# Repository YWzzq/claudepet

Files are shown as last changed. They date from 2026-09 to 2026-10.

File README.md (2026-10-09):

# AgentPet

桌面 AI Agent 状态摆件：电脑端 Claude Code / Codex 的状态经局域网 Wi-Fi 推到
ESP32-S3，通过 1.54" ST7789（240×240）表情屏幕和板载 RGB 灯显示当前状态。

支持状态配方管理、屏幕表情预览、自定义事件绑定和多会话优先级仲裁。
当前外壳为 **V5.1 像素方块版**，已完成软件几何检查，准备进行首轮打印试装。

## 当前外观与装配

下图是按硬件尺寸图生成的 CAD 模型预览。屏幕显示区构成桌宠的脸，开发板放在底层，双 USB 从右侧接线，后盖可拆卸。

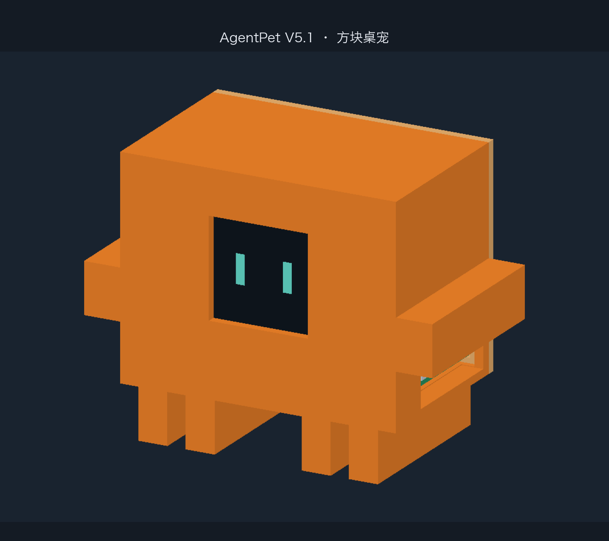
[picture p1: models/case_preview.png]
AgentPet V5.1 外壳模型预览


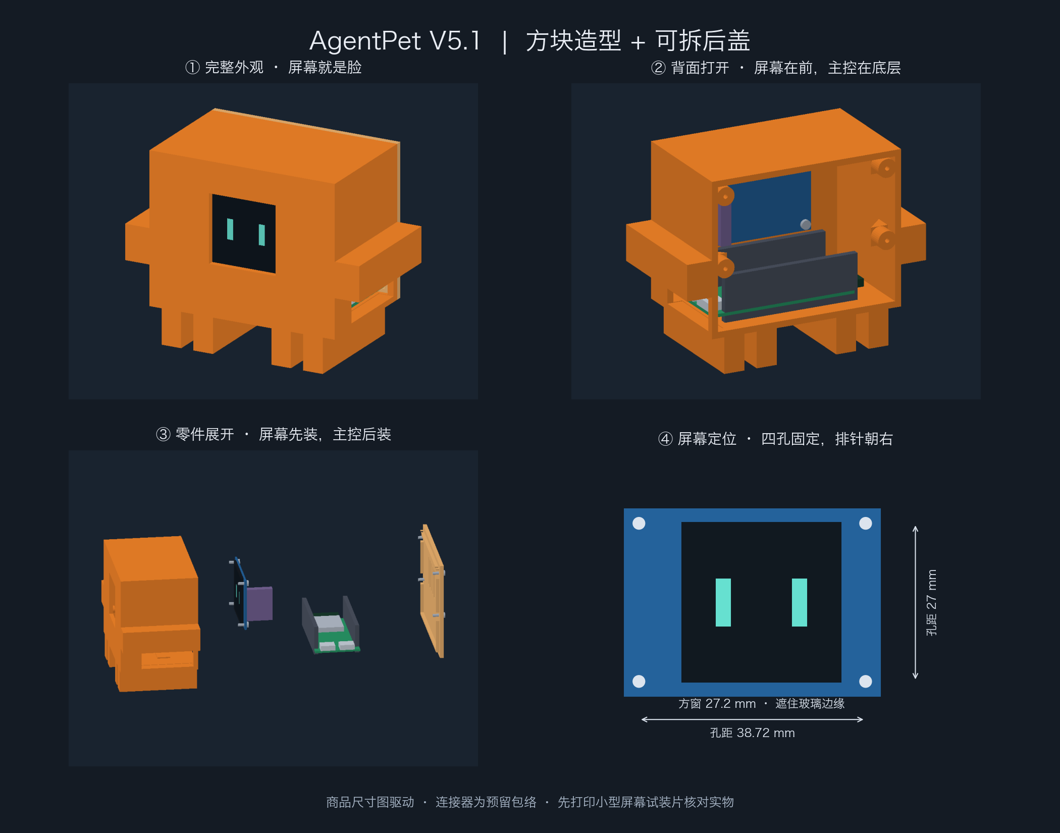
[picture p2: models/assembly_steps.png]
AgentPet V5.1 外观、内部布局、零件展开与屏幕孔位


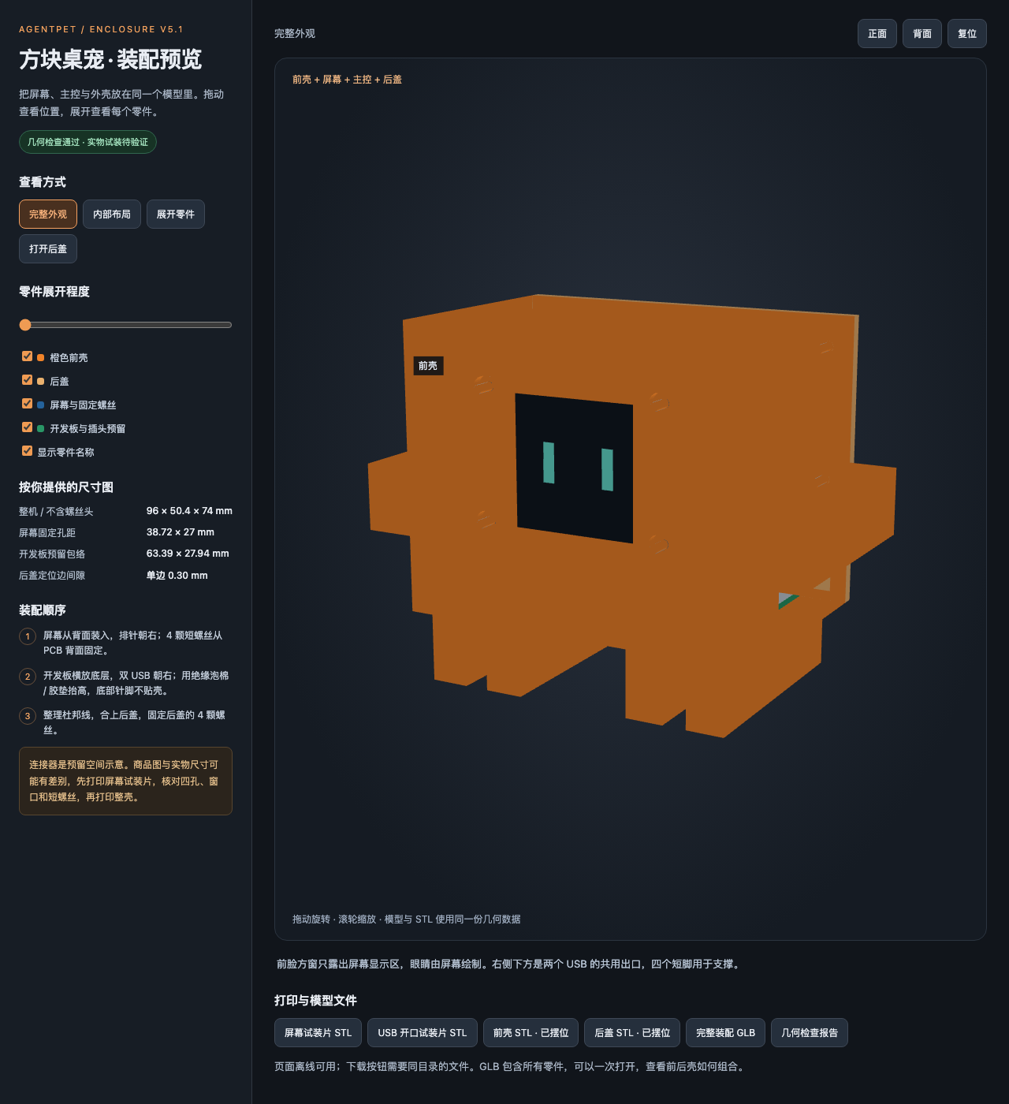
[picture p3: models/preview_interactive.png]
交互式装配预览页面


- [外壳与装配说明](models/README.md)
- [打印店专用包 V5.1](models/agentpet_print_shop_v5_1.zip)：两块试装片、前后壳、打印说明和装配图。
- [完整模型与源文件包 V5.1](models/agentpet_case_v5_1.zip)
- [完整装配 GLB](models/agentpet_assembly.glb)：一个文件查看全部零件。

下载仓库后，直接用浏览器打开 `models/assembly_preview.html`，可旋转、隐藏外壳、展开零件。
也可在项目根目录运行 `python3 -m http.server 8776 --bind 127.0.0.1 --directory models`，
然后访问 [本地装配预览](http://127.0.0.1:8776/assembly_preview.html)。GitHub 文件页显示 HTML 源码，需要下载或本地运行才能交互。

**软件检查通过不等于实物已验证。** 建议先打印屏幕和 USB 开口试装片，确认孔位、显示区及线头配合，再打印整壳。

## 系统架构

电脑端判断事件对应哪个状态，硬件端根据状态配方驱动屏幕与灯光。
事件映射保存在电脑端 `bridge/mapping.json`；状态配方保存在设备 NVS，断电保留。

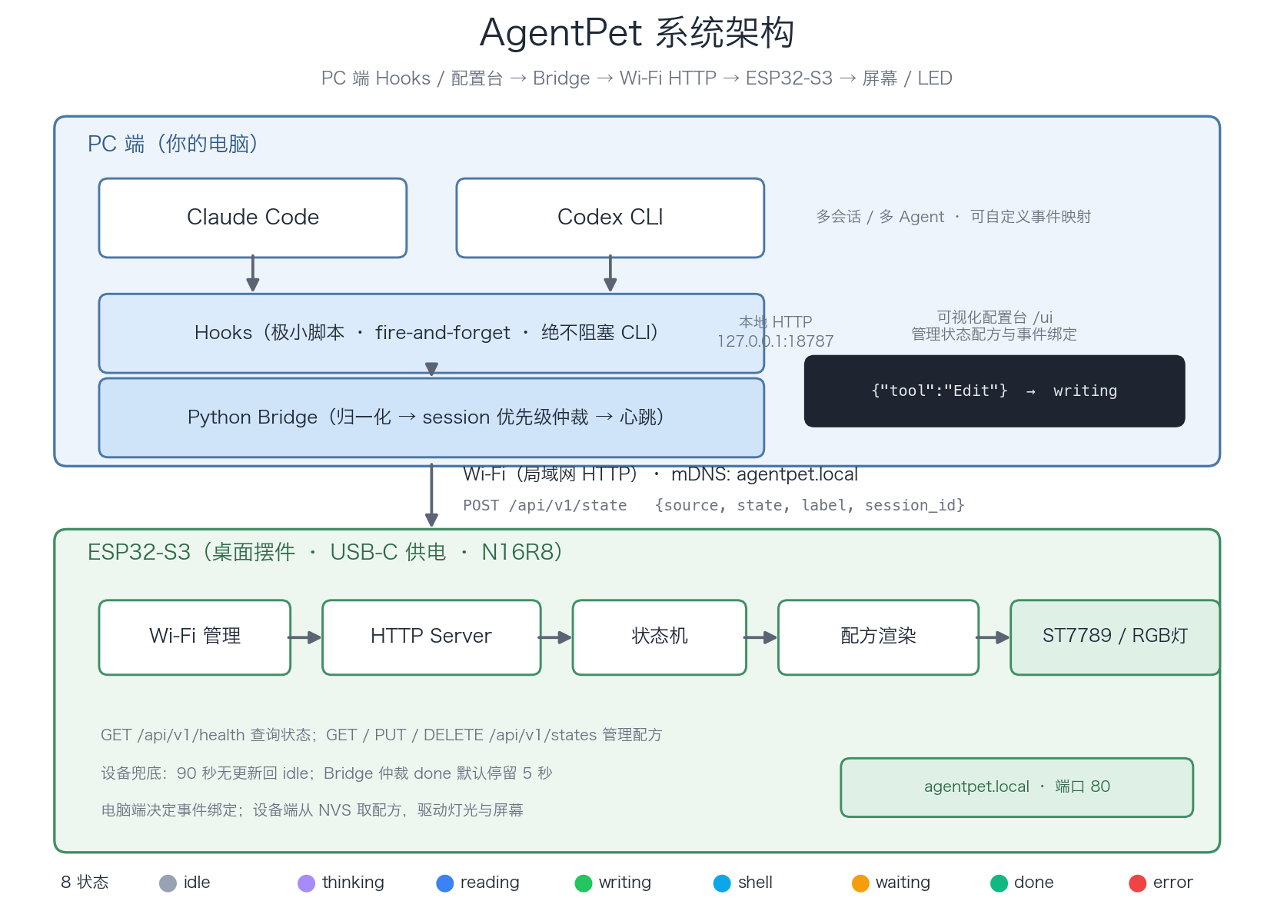
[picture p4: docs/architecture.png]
AgentPet 系统架构


## 目录结构

```
agentpet/
├── firmware/            # ESP32-S3 固件（PlatformIO + Arduino，已编译通过）
│   ├── platformio.ini
│   ├── wokwi.toml       # Wokwi 仿真入口
│   ├── diagram.json     # Wokwi 仿真接线
│   └── src/
│       ├── main.cpp     # Wi-Fi + mDNS + HTTP Server + 状态机
│       ├── pet_state.h  # 8 状态定义（与模拟器一一对应）
│       ├── display.cpp  # 矢量表情逐帧渲染（黑底彩五官，整帧推屏防闪烁）
│       ├── config.h     # 引脚 / 超时 / 设备名 / 显示开关
│       └── secrets.h.example  # 复制为 secrets.h 填 Wi-Fi
├── simulator/           # 浏览器表情模拟器（纯静态，直接打开）
├── bridge/              # Python Bridge（事件驱动推送）
│   ├── agentpet_bridge.py   # 规则引擎归一化 + session 仲裁 + 心跳
│   ├── mapping.json         # 事件→状态映射 / 优先级 / 超时（改文件热加载）
│   ├── webui.html           # 可视化配置台（bridge 自动托管）
│   └── test_bridge.py       # 单元测试（python3 test_bridge.py）
├── hooks/               # Claude Code / Codex hooks
│   ├── agentpet_hook.py     # 通用转发脚本（fire-and-forget，离线落盘）
│   └── install_hooks.py     # 一键安装器（自动备份、幂等）
├── tools/
│   └── virtual_device.py    # 虚拟 ESP32：终端表情脸，不插板子跑通全链路
├── models/              # V5.1 外壳、STL/GLB、装配预览、检查报告和打印包
│   ├── build_case.py          # 尺寸与结构的唯一来源
│   ├── render_assembly.py     # 装配图与交互预览生成器
│   ├── final_print_audit.py   # 独立检查导出的 STL / GLB
│   └── README.md             # 尺寸依据、装配与打印说明
└── docs/                # 系统架构图与生成脚本
```

## 快速开始

### 1. 表情模拟器（不需要硬件）

直接用浏览器打开 `simulator/index.html`：
8 个状态按钮切换、3 秒自动轮播、可调 `label` 和 `source`，
下方实时显示对应的 `POST /api/v1/state` 请求体。

### 2. 固件

```bash
pip install platformio
cp firmware/src/secrets.h.example firmware/src/secrets.h   # 填入 Wi-Fi
cd firmware
pio run -t upload            # 烧录（CH343P 串口，可能需要 -u 指定端口）
pio device monitor           # 看日志
```

### 3. Python Bridge（V0.5）

```bash
cd bridge
python3 test_bridge.py            # 16 个单元测试
python3 agentpet_bridge.py --demo # 演示：双会话 + 优先级抢占 + done 过期（约 16s）
python3 agentpet_bridge.py        # 正常运行，推送 http://agentpet.local
python3 agentpet_bridge.py --host 192.168.1.23   # 或手动指定设备 IP
```

手动喂一个事件（模拟 hook）：

```bash
curl -X POST http://127.0.0.1:18787/hook \
     -d '{"hook_event_name":"PreToolUse","tool_name":"Edit","session_id":"test"}'
curl http://127.0.0.1:18787/health
```

仲裁规则：`waiting > error > done > writing > shell > reading > thinking > idle`，
同优先级新的赢；done 停留 5s 后自动让位；90s 无事件的 session 丢弃。
20s 心跳兜底喂固件的 90s 超时。事件到达即时推送（事件驱动，非轮询）。

### 4. Hooks 一键安装（V0.6/V0.7）

```bash
python3 hooks/install_hooks.py             # claude + codex 都装
python3 hooks/install_hooks.py --claude    # 只装 Claude Code
```

- 安装器自动备份原配置（`.bak-时间戳`），只增不删、重复运行幂等
- hook 脚本 0.5s 超时 fire-and-forget，bridge 不在线时事件落盘
  `~/.agentpet/missed-hooks.jsonl`，绝不拖慢 CLI
- 端口冲突时：bridge `--port XXXX`，并设环境变量
  `AGENTPET_BRIDGE=http://127.0.0.1:XXXX/hook`
- 验证：开着 `bridge --dry-run`，正常使用 Claude Code，就能看到真实状态流

### 5. 用 curl 直接驱动固件（V0.4 验收，不经过 bridge）

```bash
curl -X POST http://agentpet.local/api/v1/state \
     -H 'Content-Type: application/json' \
     -d '{"source":"claude","state":"writing","label":"Edit"}'

curl http://agentpet.local/api/v1/health
```

### 6. 虚拟设备：不插板子跑通全链路

```bash
python3 tools/virtual_device.py 8080                                # 终端 A：虚拟 ESP32
AGENTPET_HOST=127.0.0.1:8080 python3 bridge/agentpet_bridge.py      # 终端 B：bridge 指向它
# 正常使用 Claude Code / Codex（或用 curl 喂 hook），终端 A 实时画表情脸
```

### 7. Wokwi 仿真（没有板子也能跑固件）

```bash
# 1) secrets.h 里 SSID 填 Wokwi-GUEST，密码留空
# 2) 编译 + 启动仿真（二选一）：
cd firmware && pio run
wokwi-cli                           # 命令行方式（需先安装 CLI、配置 token）
# 或 VS Code 装 Wokwi 扩展，打开 diagram.json 点播放
```

说明：
- **服务器仿真已部署**：wokwi-cli v0.26.1 装在服务器 `/usr/local/bin`，
  固件与配置在 `/root/agentpet/`。拿到 token 后：
  `WOKWI_CLI_TOKEN=<token> /root/agentpet/run_sim.sh`
- 本地跑也可以：`npm i -g` 不可用（CLI 不在 npm 上），用官方脚本
  `curl -L https://wokwi.com/ci/install.sh | sh`
- Wokwi 没有官方 ST7789 零件，`diagram.json` 用 `wokwi-ili9341` 代演
  （ST77xx 命令集兼容，社区通行做法；仿真屏下方留黑边属正常现象）
- wokwi-cli 自带虚拟 IoT Gateway，仿真里的固件可以访问外网乃至本机 bridge
- 仿真若颜色反色，调 `display.cpp` 里初始化后的反转设置即可

## 状态协议 v1

`POST /api/v1/state`

```json
{"source": "claude", "state": "writing", "label": "Edit", "session_id": "abc123"}
```

| state | 含义 | 表情（黑底 = 屏幕不显示，亮起的只有彩色五官） |
|---|---|---|
| idle | 空闲/睡觉 | 灰蓝：闭眼 ∪ + 飘 z |
| thinking | 思考 | 紫：眼神飘 + 平嘴 + "..." |
| reading | 读取代码 | 蓝：眼睛左右扫 |
| writing | 编辑/写代码 | 绿：眼睛向下 + o 嘴 |
| shell | 执行命令 | 青：嘴 = `> _` 提示符闪烁 |
| waiting | 等待确认/授权 | 琥珀：瞪大眼 + 嘴 = 大问号 |
| done | 任务完成 | 翠绿：笑眼 ∩ + 大笑嘴（5s 后自动回 idle） |
| error | 异常/失败 | 红：X 眼 + 波浪嘴 + 轻微抖动 |

`GET /api/v1/health` 返回：state / state_for_s / source / label / session_id /
uptime_s / wifi / rssi / heap / ip。

兜底规则：90 秒没有任何事件自动回 idle；done 停留 5 秒回 idle。

## 状态配方系统（V1.0）

板子内置"配方库"（NVS 持久化，断电不丢），出厂预置 8 个状态，支持动态增删改：

```bash
# 列出板上全部状态
curl http://agentpet.local/api/v1/states
# 新增自定义状态（灯光 + 屏幕）
curl -X PUT http://agentpet.local/api/v1/states/tea \
     -H 'Content-Type: application/json' \
     -d '{"led":{"color":"#3BC4E8","mode":"breath","period":1500},"screen":{"color":"#3BC4E8","eye":"happy"}}'
# 查看 / 删除
curl http://agentpet.local/api/v1/states/tea
curl -X DELETE http://agentpet.local/api/v1/states/tea
```

灯效 mode：`steady` 常亮 / `breath` 呼吸 / `blink` 闪烁 / `double` 双闪，
period 50~20000ms（steady 忽略）。预置状态可覆盖更新。

**bridge 事件映射**同样数据化（`bridge/mapping.json`）：规则（source/event/tool 通配/字段匹配）
→ 状态、优先级表、超时。改文件保存即热加载，不用重启。

### 可视化配置台（V1.2）

bridge 跑起来后，浏览器打开 **http://localhost:18787/ui**：

- 状态配方：管理一份状态中的灯光与屏幕配置，可新增、编辑、删除和试播。
- 灯光预览：颜色、灯效、周期；屏幕预览：五官、颜色及动画参数。
- 事件绑定：编辑 `mapping.json` 的事件映射与优先级，保存即热加载。
- 配方保存到板子 NVS；界面中的预览与试播用于检查效果，保存用于持久化。
- 板子固件已开 CORS，网页可跨域直连板子；自动从 bridge 获取板子 IP

## 屏幕接线（交接文档第 3 节）

| ST7789 | ESP32-S3 | 备注 |
|---|---|---|
| VCC / GND | 3V3 / GND | |
| SCK | GPIO12 | |
| MOSI | GPIO11 | |
| CS | GPIO10 | |
| DC | GPIO13 | |
| RST | GPIO14 | |
| BLK | 3V3（V0） | 后续可改 GPIO21 PWM 调光 |

避开：GPIO48（板载 RGB）、GPIO0（BOOT）、GPIO19/20（USB）、GPIO43/44（串口）、
GPIO35/36/37（N16R8 Octal PSRAM 占用）。

## 3D 打印外壳（V5.1）

已按屏幕与 ESP32-S3 商品尺寸图重建像素方块外壳，包含屏幕四孔固定、主控胶垫区域、双 USB 共用出口和可拆后盖。
V5.1 将主控向 USB 一侧移近 3.5 mm，USB 共用开口为 **32.34 × 12 mm**，接口后缩约 **2.8 mm**；后盖螺柱加入斜撑。

| 项目 | 当前设计 |
|---|---|
| 整机最大尺寸 | 96 × 50.4 × 74 mm，不含螺丝头 |
| 屏幕固定孔距 | 38.72 × 27 mm |
| 屏幕窗口 | 27.2 × 27.2 mm，遮住玻璃边缘 |
| 后盖定位边间隙 | 单边 0.30 mm |
| 屏幕 / 后盖螺丝 | Ø2 × 5 mm / Ø2 × 6 mm，自攻，各 4 颗 |
| 软件检查 | 54 项模型检查 + 29 项导出文件检查通过 |

打印文件按顺序使用：

1. [屏幕试装片](models/screen_fit_coupon.stl)与 [USB 开口试装片](models/usb_fit_coupon.stl)：先验证实物。
2. [前壳打印文件](models/agentpet_case_front_print.stl)与 [后盖打印文件](models/agentpet_case_back_print.stl)：试装确认后，各打印一件。文件已摆位。

首轮建议橙色 PLA / FDM、0.2 mm 层高、3 道壁、100% 比例。
打印店需要检查切片预览并按需加局部支撑；不能仅凭 STL 闭合就判断免支撑。
详见 [打印店交接说明](models/print_shop_instructions.txt)、[尺寸与装配说明](models/README.md)。
实际打印公差、插头、线材和螺丝配合仍待试装确认。

重新生成和检查模型：

```bash
python3 -m venv /tmp/agentpet-cad
/tmp/agentpet-cad/bin/pip install -r models/requirements.txt
/tmp/agentpet-cad/bin/python models/build_case.py
/tmp/agentpet-cad/bin/python models/render_assembly.py
/tmp/agentpet-cad/bin/python models/final_print_audit.py
```

## 路线图

- [x] V0.1 固件骨架：Wi-Fi + mDNS + HTTP + 状态机（编译通过）
- [x] V0.2 浏览器 240×240 表情模拟器（8 状态黑底彩五官，动画可调）
- [x] V0.3 ST7789 显示驱动与真屏配置（`AGENTPET_HAS_DISPLAY=1`；当前旋转配置为 2）
- [x] V0.4 固件矢量表情：与模拟器同一套参数移植为 Adafruit GFX（编译通过，真机观感待验证）
- [x] V0.5 Python Bridge：归一化 + session 优先级仲裁 + 心跳 + mDNS 解析（16 测试通过，事件驱动即时推送）
- [x] V0.6 Claude Code hooks：7 事件转发 + 一键安装器（沙箱安装 + 端到端验证通过）
- [x] V0.7 Codex hooks：事件归一化 + 安装器（Codex 配置格式随版本演进，不生效时按官方文档微调 `hooks/install_hooks.py`）
- [x] V0.8 外壳 V5.1：模型、装配预览、试装片、前后壳、打印包与软件检查
- [ ] V0.8 外壳实物打印与试装
- [ ] 后续动画打磨、可选电池版
- [x] V1.0 状态配方系统：配方 NVS 持久化 + GET/PUT/DELETE /states API + bridge 规则引擎（mapping.json 热加载）
- [x] V1.1 屏幕表情配方化（固件按配方 `screen` 字段驱动表情）
- [x] V1.2 可视化配置台（配方管理、屏幕 / LED 预览、事件绑定）

## 主要参考

- [clawd-mochi-esp32s3](https://github.com/TangYifu/clawd-mochi-esp32s3)：硬件完全一致
  （ESP32-S3 + 1.54" ST7789 240×240），ST7789 初始化参数与点屏细节第一参考
- [cc-mochi](https://github.com/alvis-HaoH/cc-mochi)：Claude/Codex hooks 一键安装器、
  事件归一化映射表、session 优先级、表情预览工具思路
- [VibeMonitor](https://github.com/austingregoryus/VibeMonitor)：Python Bridge、局域网 HTTP
- [Tiny Engineer](https://github.com/jamro/tiny-engineer)："设备只懂 REST" 的简单 API 设计
- [AgentDeck](https://github.com/puritysb/AgentDeck)：未来多 Agent / 多设备架构参考
- HachimoDock：桌宠 UI 与产品形态参考

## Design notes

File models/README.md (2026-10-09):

# AgentPet V5.1 外壳与试装

这一版按用户提供的橙色像素摆件外形和两张硬件尺寸图重建：平顶方块身体、两侧凸块、四只短脚。前脸的眼睛由 ST7789 绘制，外壳不另外挖眼睛孔。

**当前状态：模型几何检查通过，尚未经过实物打印和试装。** 商品尺寸图不是对用户实物的测量；先用屏幕试装片确认，不把软件检查当成“肯定刚好能装”的证明。

## 先看位置

直接双击 `assembly_preview.html`，离线也能旋转模型。切换“内部布局”“展开零件”“打开后盖”，用复选框单独隐藏零件。所有几何与 STL 同源，不是另外画的效果图。

- `assembly_steps.png`：外观、打开后盖、零件展开、屏幕定位四张图。
- `agentpet_assembly.glb`：完整装配，包含前后壳、屏幕、主控及螺丝示意。一次打开这个文件即可看到所有零件，已经转换成 glTF 的 Y 向上坐标。
- 两个 `*_print.stl` 是打印摆位；两个没有 `_print` 的 STL 保留装配坐标。`agentpet_case_both.stl` 是分开摆在打印床上的两件，不是粘成一体的外壳。

## 尺寸依据与修正

尺寸来自本次用户附件。保留足够精度定位孔位；实物精度仍需核对。

| 项目 | 本版采用 | 依据或处理 |
|---|---:|---|
| 屏幕 PCB | 32 × 43.72 mm | 参数表宽约 32，尺寸图长 43.72；31.52 是 BL 尺寸，不当成 PCB 宽度 |
| 屏幕有效显示区 AA | 27.72 × 27.72 mm | 参数表与尺寸图一致 |
| AA 相对 PCB | 从排针端 6.45 mm；从侧边 2.14 mm | 尺寸图；横置后按 AA 中心对齐方窗，PCB 中心偏左 1.55 mm |
| 四孔孔距 | 38.72 × 27.00 mm | 尺寸图；V4 的 26.52 已纠正 |
| 屏幕孔径 | Ø2.00 mm | 图中 4-Ø2.00；Ø3.80 是焊盘外圈，不能当孔径 |
| 屏模块厚度 | 2.58 mm | 参数表；PCB 自身 1.2 mm 来自侧视图 |
| 主控最大长度 | 63.389 mm | 图中 2495.63 mil × 0.0254，包含天线伸出部分 |
| 主控 PCB 长度 | 57.15 mm | 图中 2250 mil；53.34 mm 是排针跨度，不能当板长 |
| 主控最大宽度 | 27.94 mm | 尺寸图；排针中心跨度 25.40 mm |
| 完整外壳最大尺寸 | 96 × 50.4 × 74 mm | 含侧凸块、后盖与脚，不含螺丝头 |
| 主体 / 主腔宽度 | 76 / 71.2 mm | 主控总长两侧合计余量约 7.81 mm |
| 前脸窗口 | 27.2 × 27.2 mm | 遮住玻璃边缘，AA 每边遮挡 0.26 mm；并非露出整个 27.72 mm |
| 后盖定位边间隙 | 每边 0.30 mm | 打印配合假设，需试装 |

V5.1 最终检查修正：主控向右移 3.5 mm，将接口后缩从约 6.3 mm 减少到约 2.8 mm；USB 开口加宽加高，后盖螺柱增加约 45° 斜撑。

屏幕横置，排针在右边。主控横躺，天线在左边，两个 USB 朝右边。右侧是共用的约 32.34 × 12 mm 开口，两个插口都可用；插口后缩约 2.8 mm，插头是否够长仍需用实际 USB 线确认。

## 焊排针与杜邦线的预留

用户已确认：排针焊好，采用母头杜邦线。

模型预留主控 PCB 上方 14 mm 的排针 / 母头包络，下方 2.6 mm 的针脚包络；屏幕背面预留 16 mm 插头包络。主控插头最高面与屏幕插头最低面之间约 2.64 mm。灰色长条和紫色块是这些包络，**不是实际新增的塑料零件，也不是对每个接插件的精细复刻**。

主控 PCB 下表面设在 Z=20 mm，腔底 Z=16.4 mm，相差 3.6 mm。底部两块绝缘垫台高 0.8 mm，因此需要约 2.8 mm 的绝缘胶垫 / 泡棉或适当胶柱抬高板子；不要让针脚直接接触底壳。接插件实际高于预留值时，修改源文件参数后重生成。

导线没有建模。用短杜邦线从屏幕右側插头往空余侧腔走，留自然弯曲，不压排线、不拉住屏幕、不在后盖定位边内夹线；闭盖是否顺畅需要实物验证。

## 推荐的试装顺序

1. **先打印 `screen_fit_coupon.stl`**，约 50 × 37 × 4.38 mm。它复用了本版的方窗、四个螺柱和底孔。将屏幕横置、排针朝右，核对四孔是否同时对齐、玻璃是否碰柱、显示区是否正确露出。

   同时可打印 `usb_fit_coupon.stl`（约 40.34 × 20 × 2.4 mm），检查实际 USB 线塑料头能否穿过开口；它只验证开口，不验证插口深度。

2. 试装通过后打印 `agentpet_case_front_print.stl` 和 `agentpet_case_back_print.stl`。按毫米、100% 比例，不自动缩放。前壳面朝打印床，后盖外表面朝打印床，文件已摆好。
3. 从背面放入屏幕，玻璃朝窗口，4 颗螺丝从 PCB 背面拧入前壁螺柱。模型按 **Ø2 × 5 mm 短自攻螺丝**建空间，Ø1.7 mm 底孔。轻拧，不以螺丝强行拉平屏幕；不同自攻牙型和头径需在试装片上验证。原版的 6 mm 屏幕螺丝可能穿透前脸，不能直接照用。
4. 安放绝缘胶垫后，将开发板从后开口横放入底层；两个 USB 对着右侧开口。接好线，检查针脚不碰底壳、胶不覆盖插口或天线。
5. 整理杜邦线，插入后盖定位边，4 颗 **Ø2 × 6 mm 自攻螺丝**固定后盖。后盖螺柱在主控上方，避免挡住板子放入。

橙色 PLA 可作为首轮样件，层高 0.2 mm、3 道壁。前壳横跨侧边 USB 开口，请打印店检查切片预览，在 USB 开口桥接处按需加局部支撑；若支撑需要从前壁内侧生长，应允许支撑接触模型，不能只限定“仅打印床”；本版**没有承诺完全免支撑**。这两件的分开摆位约 184 × 74 mm，需要对应的打印床空间，也可各印一件。

## 软件检查覆盖什么

保存后的 STL/GLB 又通过 `final_print_audit.py` 独立检查，报告在 `final_print_audit.json`。包括实际输出的闭合性、摆位、后盖 ±0.28 mm 偏移配合、窗口与 USB 通道、四个盲底孔和屏幕螺丝末端。没有在本机运行实际打印机切片；打印店应按 `print_shop_instructions.txt` 检查切片支撑。

`fit_report.json` 包含实体闭合性、连通性、孔距、窗口范围、板子含天线尺寸、前后壳与各硬件包络的相交体积、屏幕/主控相互碰撞、USB 通道和后盖定位边。装入路径从背面到最终位置，按 1 mm 步长抽样检查，顺序是 **先屏幕、再主控、后盖最后**。

仍需实物验证：商品图与实物差异、打印收缩与孔径、胶垫、杜邦线弯曲、USB 插头外形与插入深度、螺丝牙型及长度、抗拉强度和散热。孔距通过与水密 STL 不能替代这些验证。

## 重生成

在项目根目录运行，或用绝对路径运行两个脚本；输出路径始终在 `models/`：

```sh
python3 -m venv /tmp/agentpet-cad
/tmp/agentpet-cad/bin/pip install -r models/requirements.txt
/tmp/agentpet-cad/bin/python models/build_case.py
/tmp/agentpet-cad/bin/python models/render_assembly.py
/tmp/agentpet-cad/bin/python models/final_print_audit.py
```

`build_case.py` 是尺寸与结构唯一来源；`agentpet_case.scad` 仅加载生成的 STL 用于查看。改变尺寸后应重新运行两个脚本和几何检查。手机窄屏也能打开预览，桌面浏览器能更方便地同时看到模型和控制区。

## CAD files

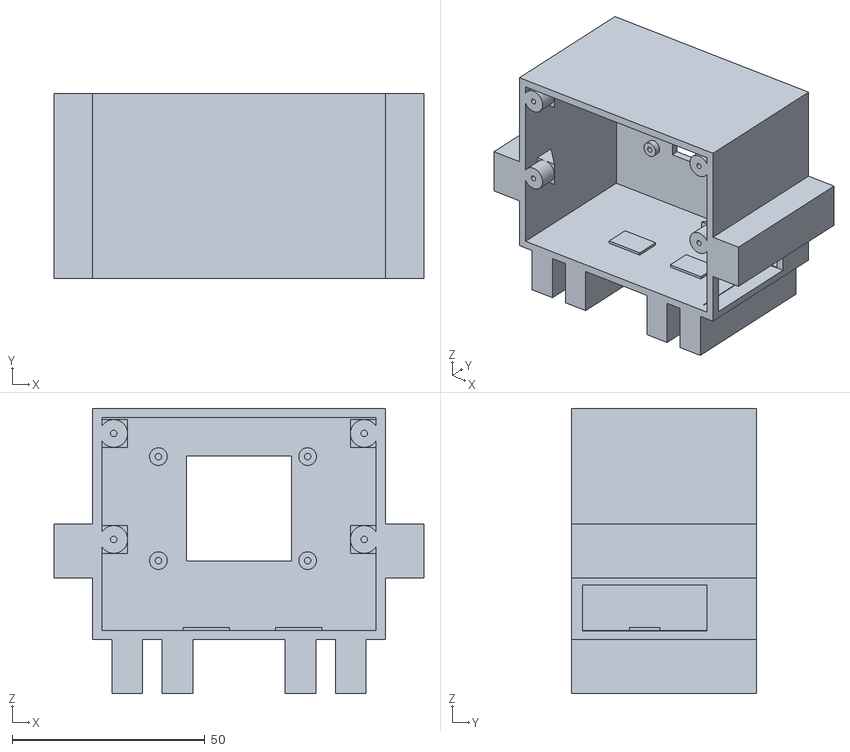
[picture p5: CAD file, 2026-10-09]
models/agentpet_case_front.stl
96.0 x 48.0 x 74.0

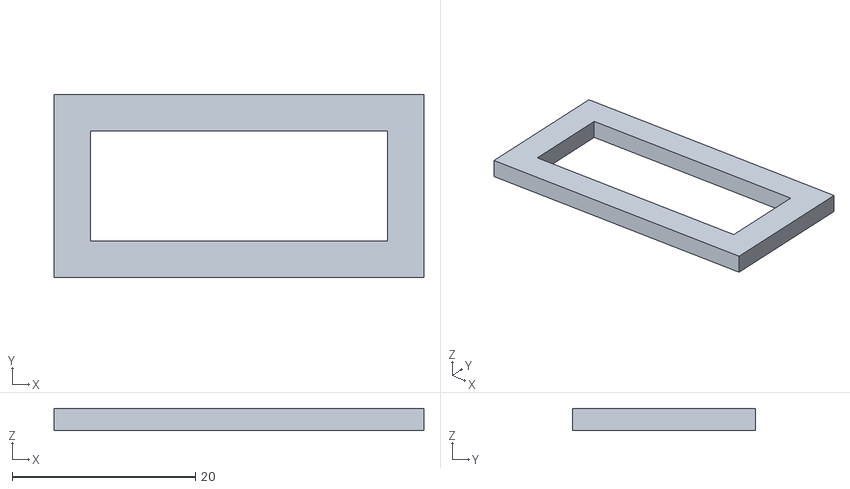
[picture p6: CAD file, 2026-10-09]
models/usb_fit_coupon.stl
40.3 x 20.0 x 2.40

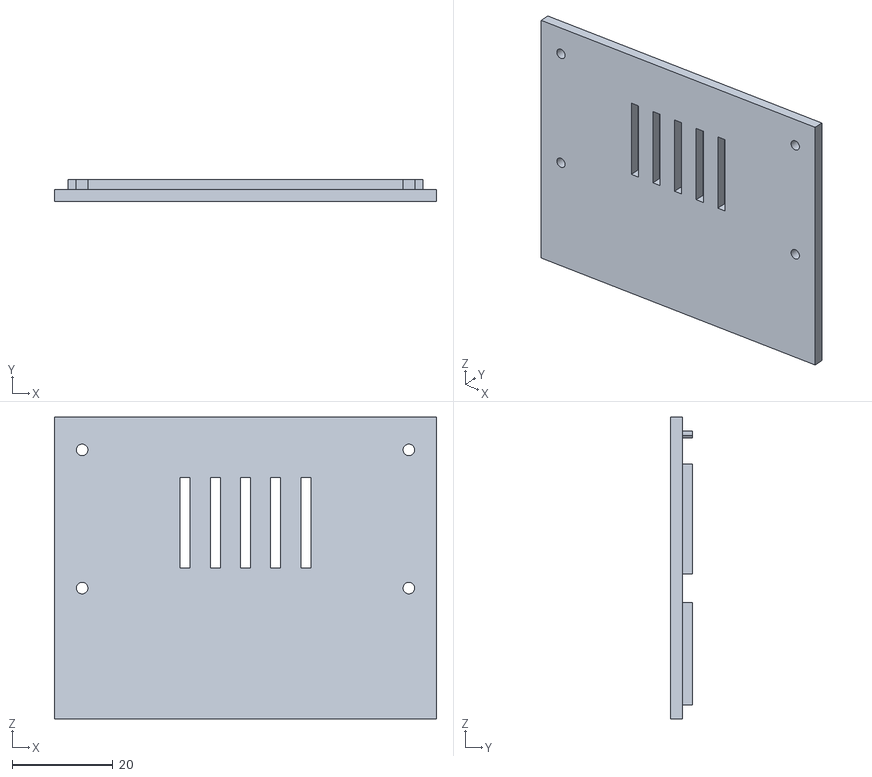
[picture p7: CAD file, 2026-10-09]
models/agentpet_case_back.stl
76.0 x 4.40 x 60.0

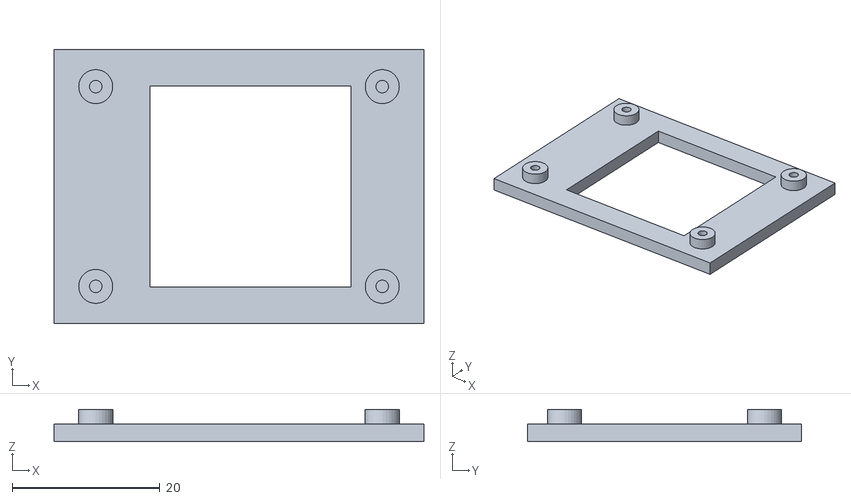
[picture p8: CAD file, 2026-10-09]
models/screen_fit_coupon.stl
50.0 x 37.0 x 4.38

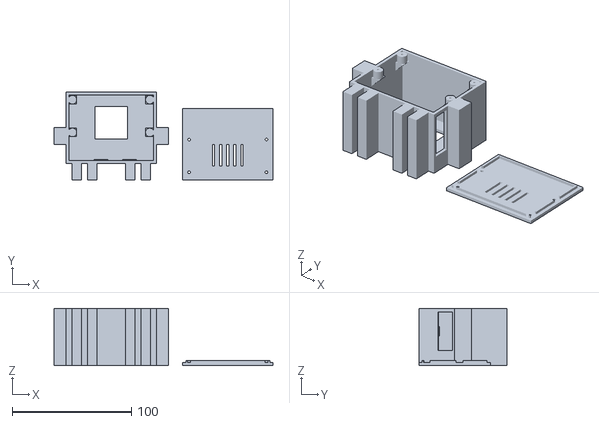
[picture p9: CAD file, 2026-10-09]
models/agentpet_case_both.stl
184.0 x 74.0 x 48.0

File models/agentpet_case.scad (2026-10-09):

// V5.1 viewer, mm. Dimension source: build_case.py; run it to regenerate meshes.
// part = "layout" | "assembly" | "front" | "back" | "coupon".
part = "layout";
if (part == "layout") import("agentpet_case_both.stl");
if (part == "assembly") {
  color("DarkOrange") import("agentpet_case_front.stl");
  color("Wheat") import("agentpet_case_back.stl");
}
if (part == "front") import("agentpet_case_front.stl");
if (part == "back") import("agentpet_case_back.stl");
if (part == "coupon") import("screen_fit_coupon.stl");

if (part == "usb-coupon") import("usb_fit_coupon.stl");

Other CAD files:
models/agentpet_case_front_print.stl
models/agentpet_case_back_print.stl

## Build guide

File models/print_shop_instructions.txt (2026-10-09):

AgentPet V5.1 打印店交接说明（2026-10-09）

工艺：FDM。材料：橙色 PLA。单位：毫米，100% 比例，不缩放。
打印一套设备外壳，不打印 GLB 里的屏幕、主控、螺丝或插头占位块。

阶段一：先各印 1 件试装片
01_screen_fit_coupon.stl：50 × 37 × 4.38 mm，验证屏幕孔位、窗口与短螺丝。
02_usb_fit_coupon.stl：40.34 × 20 × 2.4 mm，验证 USB 线塑料头能否通过开口。
试装片已经摆平。试装成功后再打印整壳。

阶段二：整壳各 1 件
03_front.stl：前壳，打印摆位尺寸 96 × 74 × 48 mm。
04_back.stl：后盖，打印摆位尺寸 76 × 60 × 4.4 mm。
两个文件已摆位且最低面为 Z=0。前壳前脸朝下，后盖外表面朝下。
整机组装尺寸 96 × 50.4 × 74 mm，不含螺丝头。

建议首轮参数：0.4 mm 喷嘴，0.2 mm 层高，3 道壁，顶底至少 4 层，15–20% 填充。
请打印店按实际机器切片确认，特别检查侧边 USB 开口的小桥接区域。
按需加局部支撑；支撑可以从模型内表面开始，不能只限定“仅打印床”。
后盖螺柱已经增加斜撑。不要填平 USB 口、屏幕窗口和后盖定位边。
保留原有孔位：前壳螺丝底孔 Ø1.7 mm，后盖通孔 Ø2.3 mm。
清理残余支撑、毛刺，避免强行扩大自攻底孔。

装配用料（不属于打印件）：
屏幕：Ø2 × 5 mm 短自攻螺丝，4 颗；先在试装片上验证牙型和头径。
后盖：Ø2 × 6 mm 自攻螺丝，4 颗。
主控：绝缘泡棉胶 / 胶垫；在底部凸台上增加约 2.8 mm 高度，底面针脚留空。
装配顺序：屏幕先装，开发板横放底层且双 USB 朝右，理线，后盖最后固定。

本包通过软件几何及导出文件检查；实物尺寸与打印公差尚未试装验证。
这是首轮试装样件，不是已经过实物验证的量产文件。
请勿使用前一版 agentpet_case_v5.zip；本次应使用 V5.1 包。

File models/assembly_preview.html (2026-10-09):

AGENTPET / ENCLOSURE V5.1

# 方块桌宠 · 装配预览

把屏幕、主控与外壳放在同一个模型里。拖动查看位置，展开查看每个零件。

几何检查通过 · 实物试装待验证

## 查看方式

完整外观内部布局展开零件打开后盖

## 零件展开程度

显示零件名称

## 按你提供的尺寸图

整机 / 不含螺丝头96 × 50.4 × 74 mm屏幕固定孔距38.72 × 27 mm开发板预留包络63.39 × 27.94 mm后盖定位边间隙单边 0.30 mm

## 装配顺序

1屏幕从背面装入，排针朝右；4 颗短螺丝从 PCB 背面固定。

2开发板横放底层，双 USB 朝右；用绝缘泡棉 / 胶垫抬高，底部针脚不贴壳。

3整理杜邦线，合上后盖，固定后盖的 4 颗螺丝。

连接器是预留空间示意。商品图与实物尺寸可能有差别，先打印屏幕试装片，核对四孔、窗口和短螺丝，再打印整壳。

完整外观

正面背面复位

外观内部展开后盖

前壳 + 屏幕 + 主控 + 后盖

拖动旋转 · 滚轮缩放 · 模型与 STL 使用同一份几何数据

前脸方窗只露出屏幕显示区，眼睛由屏幕绘制。右侧下方是两个 USB 的共用出口，四个短脚用于支撑。

## 打印与模型文件

屏幕试装片 STLUSB 开口试装片 STL前壳 STL · 已摆位后盖 STL · 已摆位完整装配 GLB几何检查报告

页面离线可用；下载按钮需要同目录的文件。GLB 包含所有零件，可以一次打开，查看前后壳如何组合。

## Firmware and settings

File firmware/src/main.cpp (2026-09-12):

/**
 * AgentPet V1.0 固件
 * Wi-Fi + mDNS + HTTP + 配方驱动状态机
 *
 * 状态不再是写死的枚举：板子内置"配方库"（NVS 持久化，出厂预置 8 态），
 * 收到的 state 名字先查配方库，按配方渲染 LED 与屏幕。
 *
 * 路由：
 *   POST   /api/v1/state            {"state":"writing","source":"claude",...}
 *   GET    /api/v1/states           列出全部状态配方
 *   GET    /api/v1/states/<name>    查看单个配方
 *   PUT    /api/v1/states/<name>    新增/覆盖配方（存 NVS，断电不丢）
 *   DELETE /api/v1/states/<name>    删除配方
 *   GET    /api/v1/health           健康检查
 *
 * 烧录前：复制 src/secrets.h.example 为 src/secrets.h 并填入 Wi-Fi 信息
 */
#include <Arduino.h>
#include <ESPmDNS.h>
#include <WebServer.h>
#include <WiFi.h>
#include <ArduinoJson.h>

#include "config.h"
#include "display.h"
#include "pet_state.h"
#include "recipe_store.h"
#include "secrets.h"
#include "status_led.h"

WebServer server(HTTP_PORT);

RecipeStore gRecipes;
String gStateName = "idle";
String gSource, gLabel, gSession;
unsigned long gStateSince = 0;             // 当前状态开始时间
unsigned long gLastEvent = 0;              // 最近一次收到 state POST
String gRendered = "";                     // 上次已渲染的状态名

void setState(const String& name, const String& source, const String& label, const String& session) {
  gStateName = name;
  gSource = source;
  gLabel = label;
  gSession = session;
  gStateSince = gLastEvent = millis();

  // 配方驱动：查库取渲染参数（查不到回落 idle，理论上有 API 校验不会发生）
  StateRecipe sr;
  if (!gRecipes.get(name, sr)) gRecipes.get("idle", sr);
  ledApplyRecipe(sr.led);

  // 屏幕：配方参数驱动（内置表情表 + 配方 screen 覆盖）
  displaySetStateByName(name, label, sr.raw);
}

void handleState() {
  if (!server.hasArg("plain")) {
    server.send(400, "application/json", "{\"error\":\"missing body\"}");
    return;
  }
  JsonDocument doc;
  if (deserializeJson(doc, server.arg("plain"))) {
    server.send(400, "application/json", "{\"error\":\"invalid json\"}");
    return;
  }
  String name = String(doc["state"] | "");
  if (!gRecipes.has(name)) {
    server.send(404, "application/json",
                ("{\"error\":\"unknown state: " + name + "\"}").c_str());
    return;
  }
  setState(name, String(doc["source"] | ""), String(doc["label"] | ""),
           String(doc["session_id"] | ""));
  JsonDocument resp;
  resp["ok"] = true;
  resp["state"] = name;
  String out;
  serializeJson(resp, out);
  server.send(200, "application/json", out);
}

void handleStatesList() {
  server.send(200, "application/json", gRecipes.listJson());
}

// /api/v1/states/<name> 的 GET / PUT / DELETE
void handleStateItem() {
  // 浏览器跨域预检：任何路径的 OPTIONS 都直接放行（CORS 头由 enableCORS 附加）
  if (server.method() == HTTP_OPTIONS) {
    server.send(200, "application/json", "{}");
    return;
  }
  String prefix = String("/api/v1/states/");
  String uri = server.uri();
  if (!uri.startsWith(prefix)) {
    server.send(404, "application/json", "{\"error\":\"not found\"}");
    return;
  }
  String name = uri.substring(prefix.length());
  if (!RecipeStore::validName(name)) {
    server.send(400, "application/json", "{\"error\":\"invalid name\"}");
    return;
  }

  switch (server.method()) {
    case HTTP_GET: {
      StateRecipe r;
      if (!gRecipes.get(name, r)) {
        server.send(404, "application/json", "{\"error\":\"no such state\"}");
        return;
      }
      server.send(200, "application/json", r.raw);
      return;
    }
    case HTTP_PUT: {
      String body = server.arg("plain");
      String err;
      if (gRecipes.put(name, body, err)) {
        String out = "{\"ok\":true,\"state\":\"" + name + "\"}";
        server.send(200, "application/json", out);
      } else {
        String out = "{\"error\":\"" + err + "\"}";
        server.send(400, "application/json", out);
      }
      return;
    }
    case HTTP_DELETE: {
      bool ok = gRecipes.remove(name);
      server.send(ok ? 200 : 404, "application/json",
                  ok ? "{\"ok\":true}" : "{\"error\":\"no such state\"}");
      return;
    }
    default:
      server.send(405, "application/json", "{\"error\":\"method not allowed\"}");
  }
}

void handleHealth() {
  JsonDocument doc;
  doc["device"] = DEVICE_NAME;
  doc["state"] = gStateName;
  doc["state_for_s"] = (millis() - gStateSince) / 1000;
  doc["source"] = gSource;
  doc["label"] = gLabel;
  doc["session_id"] = gSession;
  doc["uptime_s"] = millis() / 1000;
  doc["wifi"] = (WiFi.status() == WL_CONNECTED) ? "connected" : "disconnected";
  doc["rssi"] = WiFi.RSSI();
  doc["heap"] = ESP.getFreeHeap();
  doc["ip"] = WiFi.localIP().toString();
  doc["states"] = gRecipes.count();
  String out;
  serializeJson(doc, out);
  server.send(200, "application/json", out);
}

void connectWiFi() {
  WiFi.mode(WIFI_STA);
  WiFi.setSleep(false);  // 状态推送走低延迟路径，关闭 Wi-Fi 休眠
  WiFi.begin(WIFI_SSID, WIFI_PASSWORD);
  Serial.printf("[wifi] connecting to %s ", WIFI_SSID);
  unsigned long t0 = millis();
  while (WiFi.status() != WL_CONNECTED && millis() - t0 < 20000) {
    delay(250);
    Serial.print(".");
  }
  if (WiFi.status() == WL_CONNECTED) {
    Serial.printf("\n[wifi] connected, ip=%s rssi=%ddBm\n",
                  WiFi.localIP().toString().c_str(), WiFi.RSSI());
    if (MDNS.begin(DEVICE_NAME)) {
      MDNS.addService("http", "tcp", HTTP_PORT);
      Serial.printf("[mdns] http://%s.local\n", DEVICE_NAME);
    }
  } else {
    Serial.println("\n[wifi] connect failed, will retry in loop()");
  }
}

void setup() {
  Serial.begin(115200);
  delay(200);
  gRecipes.begin();  // NVS 配方库（首次启动播种 8 个预置状态）
  ledBegin(gRecipes, "idle");
  displayInit();
  connectWiFi();

  server.on("/api/v1/state", HTTP_POST, handleState);
  server.on("/api/v1/states", HTTP_GET, handleStatesList);
  server.on("/api/v1/health", HTTP_GET, handleHealth);
  server.on("/", HTTP_GET, []() {
    server.send(200, "text/plain",
                "AgentPet V1.0 - POST /api/v1/state, GET/PUT/DELETE /api/v1/states/<name>, GET /api/v1/health");
  });
  // 动态路径 /api/v1/states/<name> 与兜底 404
  server.onNotFound(handleStateItem);
  server.enableCORS(true);  // 允许网页配置台跨域直连板子
  server.begin();

  setState("idle", "", "", "");
  Serial.println("[app] AgentPet V1.0 ready");
}

void loop() {
  server.handleClient();

  // Wi-Fi 断线自动重连
  static unsigned long lastWifiCheck = 0;
  if (millis() - lastWifiCheck > WIFI_RETRY_MS) {
    lastWifiCheck = millis();
    if (WiFi.status() != WL_CONNECTED) {
      Serial.println("[wifi] reconnecting...");
      WiFi.reconnect();
    }
  }

  // 兜底回落：长时间无事件回 idle（done 的短停留由 bridge 侧管理）
  if (gStateName != "idle" && millis() - gLastEvent > STATE_TIMEOUT_MS) {
    Serial.println("[app] state timeout -> idle");
    setState("idle", "", "", "");
  }

  // 状态切换日志
  if (gStateName != gRendered) {
    Serial.printf("[app] state -> %s (source=%s label=%s)\n",
                  gStateName.c_str(), gSource.c_str(), gLabel.c_str());
    gRendered = gStateName;
  }

  // 约 15fps 的动画帧率，眨眼/扫读/光标闪烁全程非阻塞
  static unsigned long lastFrame = 0;
  if (millis() - lastFrame >= 66) {
    lastFrame = millis();
    displayRender();
  }
  ledRender();  // 状态灯灯效（内部 20ms 节流，独立于屏幕节拍更顺滑）

#ifdef AGENTPET_SIM_DEMO
  // 仿真演示模式：每 6 秒轮流展示预置状态（Wokwi 截图验证用，真机构建不含此代码）
  static unsigned long lastDemo = 0;
  static uint8_t demoIdx = 0;
  if (millis() - lastDemo > 6000) {
    lastDemo = millis();
    setState(petStateName((PetState)(demoIdx % PET_STATE_COUNT)), "demo", "", "");
    demoIdx++;
  }
#endif
}

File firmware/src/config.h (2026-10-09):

#pragma once

// ── 设备标识 ──
#define DEVICE_NAME  "agentpet"   // mDNS 注册后可访问 http://agentpet.local
#define HTTP_PORT    80

// ── ST7789 接线（交接文档第 3 节）──
#define PIN_LCD_SCK   12
#define PIN_LCD_MOSI  11
#define PIN_LCD_CS    10
#define PIN_LCD_DC    13
#define PIN_LCD_RST   14
#define PIN_LCD_BL    21   // V0 硬件上 BLK 直接接 3V3 常亮；以后改接 GPIO21 可 PWM 调光

// ── 板载状态灯 ──
#define PIN_RGB_LED 48       // 板载 WS2812
#define LED_MAX_BRIGHTNESS 16 // 亮度上限 0~255（≈6%，WS2812 很亮，室内够用不刺眼）

// ── 状态兜底 ──
#define STATE_TIMEOUT_MS  (90 * 1000UL)   // 超过这么久没有任何新事件 → 回 idle
#define DONE_HOLD_MS      (5 * 1000UL)    // done 表情展示时长，之后自动回 idle
#define WIFI_RETRY_MS     (10 * 1000UL)   // Wi-Fi 断线重连检查间隔

// ── 显示开关 ──
// 1 = 驱动 ST7789 真屏 / Wokwi 仿真屏；0 = 只打串口日志
// （当前屏幕未接线，先开启待命；插上屏幕后按 RST 即点亮）
#define AGENTPET_HAS_DISPLAY 1

// IPS 屏颜色反转：大多数 1.54" ST7789 IPS 模块需要 1（否则黑变白）。
// 注意：Wokwi 仿真屏强制 IPS 反转且处理方式不同，仿真用 simdemo 固件（invert=0 + rotation=0）。
// 真机若反色，在 1/0 之间切换试出正确值。
#ifndef LCD_INVERT
#define LCD_INVERT 1
#endif

// 屏幕旋转方向 0~3，按摆件安装方向调整
#ifndef LCD_ROTATION
#define LCD_ROTATION 2
#endif

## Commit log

2026-09-12 AgentPet V1.0: 桌面 AI Agent 状态摆件
    - 固件 (ESP32-S3): Wi-Fi/mDNS/HTTP + 配方驱动状态机 + NVS 配方库 + 状态灯
    - bridge: 规则引擎归一化(mapping.json 热加载) + session 仲裁 + 事件驱动推送
    - hooks: Claude Code 7 事件 + Codex notify 分发器, 一键安装器
    - simulator: 240x240 浏览器表情模拟器
    - webui: 可视化配置台(配方管理/绑定规则/实时预览)
    - docs: 架构图与说明书
2026-09-12 V1.2 可视化配置台 + V1.0 配方系统完善
    - webui 双页签: 状态配方(灯光+屏幕合一编辑, LED/屏幕实时预览) + 事件绑定(规则卡片化/优先级/超时)
    - 固件: RecipeStore(NVS 配方库) + GET/PUT/DELETE /api/v1/states API + CORS/OPTIONS
    - bridge: mapping.json 规则引擎(通配符/条件字段/优先级) + 热加载 + 配置台托管
2026-09-12 V1.1 屏幕参数化渲染 + 经典表情库扩充至 16 态
    - 固件: 屏幕渲染改为配方参数驱动(背景/眼睛8种/眼神4种/嘴9种/附加7种/抖动)
    - 固件: 新增 8 个经典表情 angry/love/cry/dizzy/cool/shy/tongue/shock
    - 固件: NVS 增量播种(升级固件自动补新预置态, 自定义配方与断电持久化不受影响)
    - webui: 屏幕预览面板(参数实时渲染) + 编辑项扩充, 保存随配方写入 NVS
    - bridge: 规则引擎支持 tool 通配符/条件字段/优先级覆盖(mapping.json 热加载)
2026-10-09 V0.3/V0.4 真机点屏: ST7789 表情渲染上屏, 16 状态轮播验收通过
    - AGENTPET_HAS_DISPLAY=1 启用屏幕驱动, invert/rotation 一次到位无需调整
    - 全链路验证: hook → bridge → Wi-Fi → 屏幕+RGB 灯联动
    - 屏幕侧渲染与配置台预览/模拟器三端同源, 改配方即改表情
    [config.h, display.cpp]
2026-10-09 V0.8 外壳: 参数化模型(scad) + STL 生成器(trimesh) + 预览
    - 前后壳分离, 四角 M2 螺柱, 屏窗/USB口/RGB导光孔/散热缝
    - 尺寸参数集中在文件头部, 实测后一处调整即可重出 STL
    [agentpet_case.scad, agentpet_case_back.stl, agentpet_case_front.stl]
2026-10-09 V0.8 外壳 V3: 按商品页实测尺寸重建 + 装配可视化
    - 硬件实测: 板 53.34x27.94, 屏面板 32x43.7/显示区27.72
    - 布局: 板横卧底层(USB朝右壁), 屏竖贴前窗内侧, 背板顶部插入式
    - 修正: 屏窗/USB口打穿外壁, 屏幕高度(外壳加高至50mm), 卡扣避让
    - 新增 assembly_steps.png 四步装配图 + render_assembly.py
    [agentpet_case_back.stl, agentpet_case_both.stl, agentpet_case_front.stl]
2026-10-09 V0.8 外壳 V3.1: 屏幕螺丝孔精确定位版(按官方尺寸图)
    - 屏幕横置(43.7长边水平), 下缘插底板卡槽定位, 上方2孔锁M2自攻
    - 屏窗 28.2mm 严格只露显示区(27.72), PCB边缘全隐藏
    - 板子热熔胶/双面胶粘底板, 四角限位凸台; USB右侧出线
    - 整体缩至 62.8x38.8x36mm; 附装配步骤图
    [agentpet_case_back.stl, agentpet_case_both.stl, agentpet_case_front.stl]
2026-10-09 V0.8 外壳 V4: 像素风 Clawd 吉祥物造型
    - 8x8 像素格剪影(格10mm): 双腿/身体/两侧钳臂/顶部呆毛, 80x80x38.8mm
    - 屏幕横置嵌脸部窗口(28.2 只露显示区), 4 孔对 4 条侧壁托臂 M2 自攻
    - 板子横卧底层热熔胶固定, USB 右壁出线; 像素背板带通风孔
    - build_case.py 重写为像素网格生成器 + 装配步骤图
    [agentpet_case_back.stl, agentpet_case_front.stl]
2026-10-09 V5.1 外壳: 按官方尺寸图重建 + 试装验证体系(外部协作者迭代)
    - 尺寸修正: 板长63.39含天线(53.34是排针跨度), 屏PCB 32x43.72,
    孔距38.72x27.00(V4的26.52已纠正), 孔径Ø2.0(3.8是焊盘)
    - 新增: screen_fit_coupon.stl 试装片 / USB开口试装片 / 打印摆位 STL
    - 新增: fit_report.json 50项几何检查 / artifact_manifest.json SHA256 清单
    - 新增: assembly_preview.html 离线交互预览 + agentpet_assembly.glb
    - 新增: 打印店专用包 agentpet_print_shop_v5_1.zip 与完整源文件包
    - 整机 96x50.4x74mm, 屏窗27.2 只露显示区, 双USB共用右侧开口
    - README: V5.1 章节与交互预览截图
    [agentpet_case.scad, agentpet_case_back.stl, agentpet_case_back_print.stl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]
2026-10-09 Fix V5.2 enclosure clearance for front-side screen header pins
2026-10-09 Use glass height for front pins and retain existing 0.6 mm clearance
2026-10-09 Add dimensioned screen and ESP32-S3 models with virtual assembly preview
2026-10-09 Keep hardware assembly preview fully visible in the browser
2026-10-10 fix(models): remove tiny rear lip islands for V5.3 print
2026-10-12 fix(firmware): rotate mounted screen clockwise by 90 degrees
2026-10-12 Add Claude pixel expression collection and reliable local UI device proxy
